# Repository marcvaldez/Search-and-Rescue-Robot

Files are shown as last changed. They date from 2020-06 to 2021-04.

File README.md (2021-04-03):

# Search-and-Rescue-Robot
A project created as a requirement for my mechatronics class in NBCC

Click on the image below to see the robot in action.

<a href="http://www.youtube.com/watch?feature=player_embedded&v=D-dJUbFVb4I
" target="_blank">Search and Rescue Robot</a>

Click on the image below for an overview
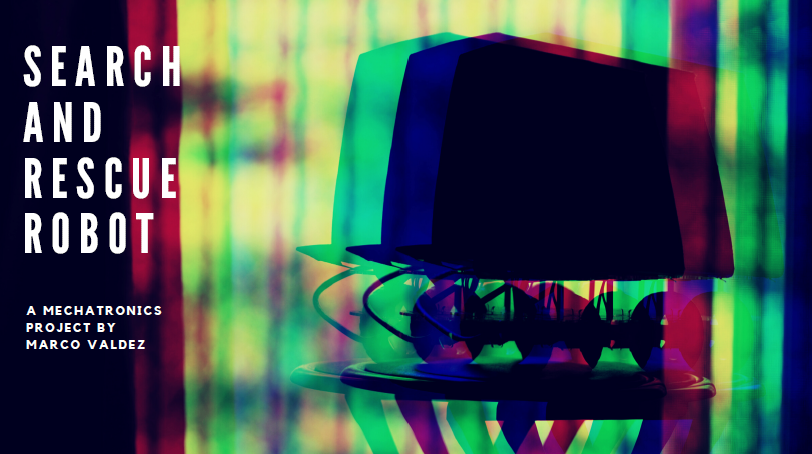
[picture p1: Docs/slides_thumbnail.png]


## Features

- Can be controlled via wi-fi using a laptop or phone or any device that has a browser
- Has a camera for first-person view
- Has collision detection through the ultrasonic sensor so that it would automatically stop when it's about to hit an obstacle
- Able to recognize specific objects to assist in searching (via an external object detection server)
- Armed with a foam dart pistol and laser module for dealing with threats

## Controls

- Forward
- Backward
- Turn Left
- Turn Right
- Nudge Left
- Nudge Right
- Stop
- Toggle Laser
- Fire Weapon

## Parts

- Arduino Uno
- ESP32-Cam microcontroller
- Robot Car Chassis with 4x DC motors and gearboxes (without motor driver circuitboard)
- 4-channel relay
- USB Power Bank
- Laser Module
- Ultrasonic Sensor
- Micro servo
- Ceramic capacitors
- Foam dart gun
- Breadboard

## Installation

### Step 1

Follow the steps in this YouTube tutorial by Edje Electronics

<a href="http://www.youtube.com/watch?feature=player_embedded&v=Rgpfk6eYxJA
" target="_blank">Object Detection Tutorial Video Thumbnail</a>

on how to create a Tensorflow v1 environment and train an object detection model to be able to recognize your "search targets".

Tip: I found that running `conda install tensorflow-gpu=1.15.0` is a quick shortcut to setting up your tensorflow environment. No need to install CUDA or cuDNN, etc.

### Step 2

Copy `object_detection_server.py` from this project into your `tensorflow/models/research/object_detection` folder and run it.

### Step 3

Modify `Arduino/RobotEye/index.html` and replace the values for cam_ws and ai_ws with the intended IP addresses of your robot server and object detection server.

This `index.html` will serve as the "remote control" or UI of the robot. You have two options on where to host this html file:

#### Option 1 - Hosting the UI on the image detection server

Just copy the modified file over to the same location where you copied `object_detection_server.py` which is your `tensorflow/models/research/object_detection` folder.

#### Option 2 - Hosting the UI on the robot itself

This step is a bit more involved. First, compress all the text content of the modified `index.html` using gzip and encode it in a comma-separated hex (0x00) format. You can do this easily using [CyberChef](https://gchq.github.io/CyberChef).

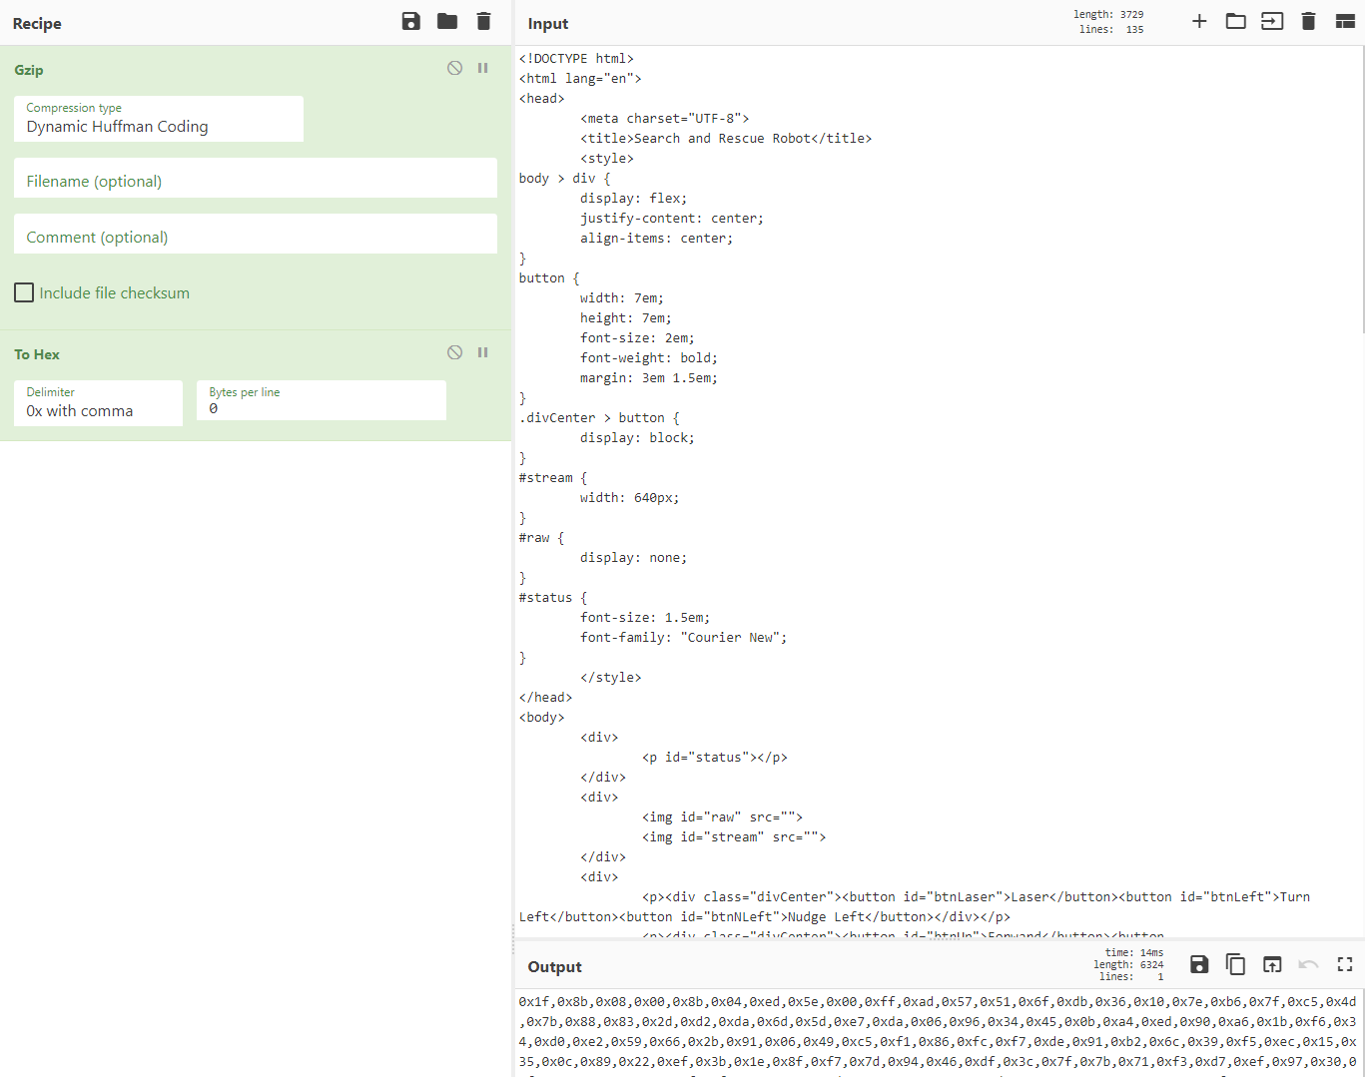
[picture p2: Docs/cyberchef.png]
CyberChef screenshot


Then, modify the `Arduino/RobotEye/camera_index.h` and replace all the hex code with the output from CyberChef. Don't forget to change the value of `index_ov2640_html_gz_len` to the number of hex codes you got. (I usually just paste all the hex code in Notepad++ and find the last column and divide by 5.)

#### Bonus Option - Do both options

### Step 4

Modify `Arduino/RobotEye/RobotEye.ino` by putting your wi-fi SSID and password into the code.

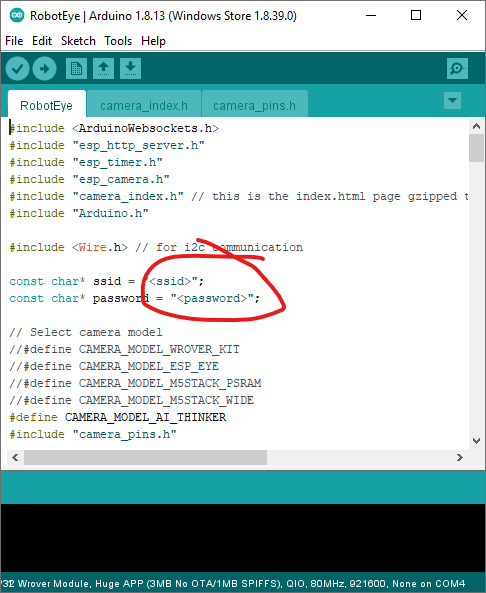
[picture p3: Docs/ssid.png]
Robot eye code screenshot


Make sure you have the ESP32 boards installed in the Arduino IDE. If not, go to `File-Preferences` and make sure `https://dl.espressif.com/dl/package_esp32_index.json` is included under `Additional Boards Manager URLs`.

Board manager

Upload `Arduino/RobotEye/RobotEye.ino` to the ESP32-Cam. Use ESP32 Wrover Module as the board when uploading. Try to use a partition with a high enough space for the app. "Huge App" works fine.

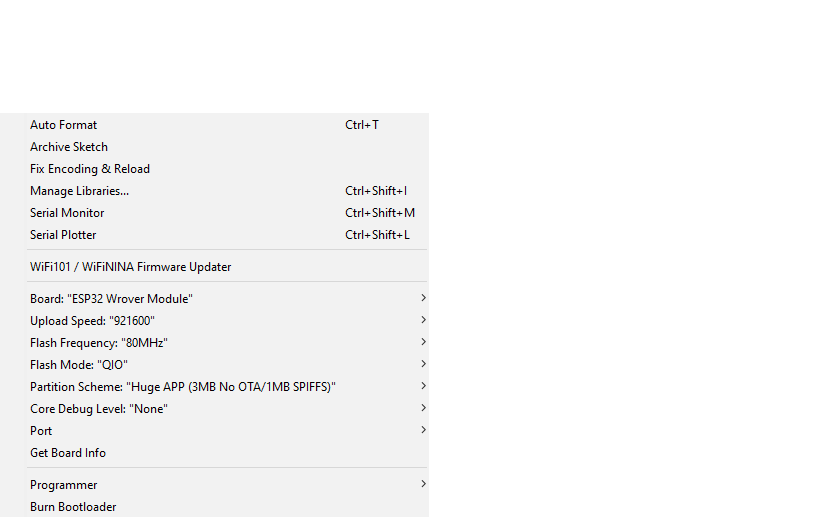
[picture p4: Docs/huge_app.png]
Upload screen


If you do not have an FTDI programmer or any other way to upload code to the ESP32-Cam. Refer to the tutorial below on how to program the ESP32-Cam using just the Arduino Uno.

https://create.arduino.cc/projecthub/PMGOHARIAN/setting-up-esp-cam-with-arduino-no-more-usb-ttl-35467a

### Step 5

Upload `Arduino/RobotEngine/RobotEngine.ino` to the Arduino Uno.

### Step 6

Wire everything up using the Fritzing diagram in `Docs\Search_and_Destroy_Robot.fzz`
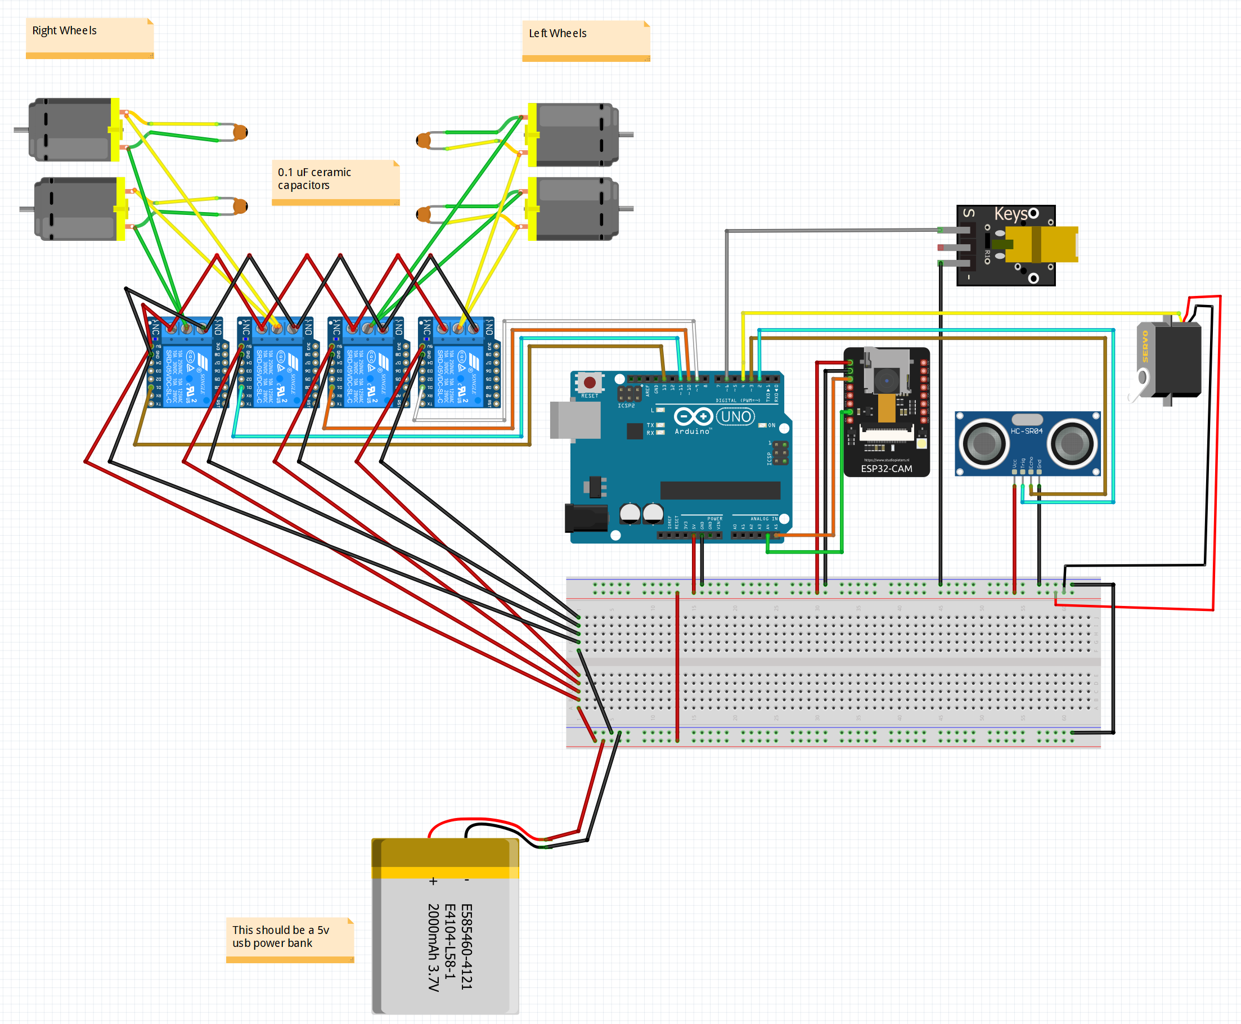
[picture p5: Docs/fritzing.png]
Fritzing Diagram


### Step 7

Navigate to wherever you hosted the "Remote Control" UI html page from step 3 using your browser and enjoy searching and rescuing.

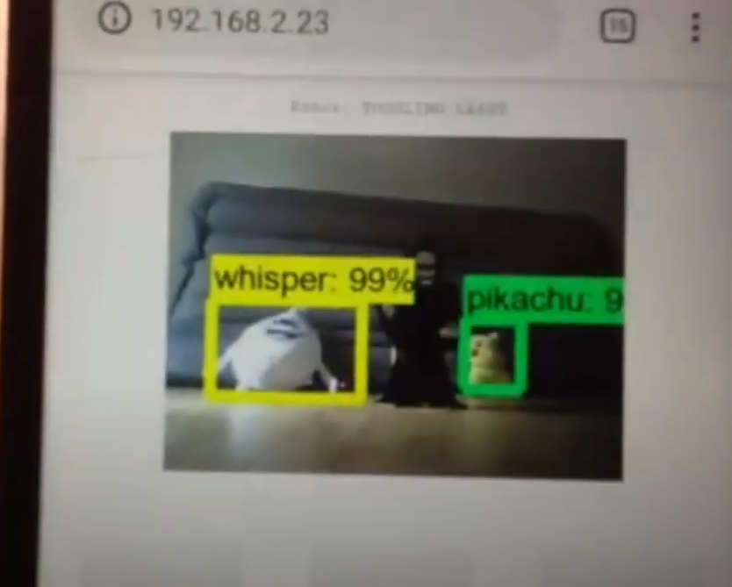
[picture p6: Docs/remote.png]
Remote UI image


## References

DC Motor Controller with Two Relays
https://www.instructables.com/id/DC-Motor-Controller-With-Two-Relay/

Programming ESP32-CAM with the Arduino Uno Without FTDI or USB-TTL
https://create.arduino.cc/projecthub/PMGOHARIAN/setting-up-esp-cam-with-arduino-no-more-usb-ttl-35467a

I2C Between Arduinos
https://www.instructables.com/id/I2C-between-Arduinos/

Editing the ESP32-CAM Camera Web Server HTML
https://robotzero.one/esp32-cam-custom-html/

Tensorflow Object Detection Tutorial
https://github.com/EdjeElectronics/TensorFlow-Object-Detection-API-Tutorial-Train-Multiple-Objects-Windows-10

How to Create a Simple Python WebSocket Server Using Tornado
https://www.toptal.com/tornado/simple-python-websocket-server

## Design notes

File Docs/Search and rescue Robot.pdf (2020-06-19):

# A M E C H A T R O N I C S P R O J E C T B Y M A R C O V A L D E Z

# SEARCH AND RESCUE ROBOT

# FEATURES

Can be controlled via wi-fi using a laptop or phone or any

device that has a browser

Has a camera for first-person view

Has collision detection through the ultrasonic sensor so that it

would automatically stop when it's about to hit an obstacle

Able to recognize specific objects to assist in searching (via an

object detection server)

Armed with a foam dart pistol and laser module for dealing with

threats

Forward

Backward

Turn Left

Turn Right

Nudge Left

Nudge Right

Stop
Toggle Laser

Fire Weapon

# CONTROLS

# HOW IT WORKS

### Device with Browser

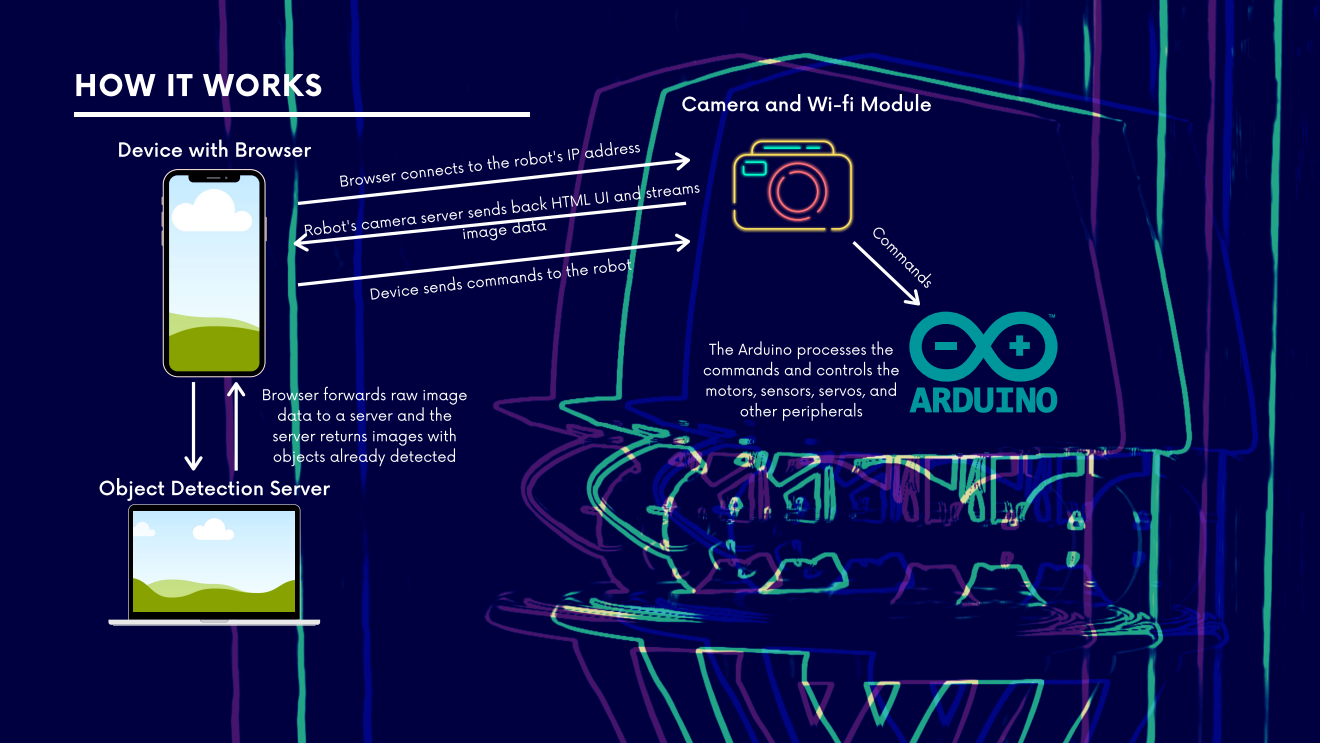
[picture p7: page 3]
image data; Commands; other peripherals

Camera and Wi-fi Module

Browser connects to the robot's IP address

Robot's camera server sends back HTML UI and streams

Device sends commands to the robot

The Arduino processes the
commands and controls the
motors, sensors, servos, and

Browser forwards raw image
data to a server and the
server returns images with
objects already detected

Object Detection Server

# PARTS

Arduino Uno

ESP32-Cam microcontroller - https://www.amazon.ca/gp/product/B07WTBTKDM

Robot Car Chassis with 4x DC motors and gearboxes - https://www.amazon.ca/gp/product/B075LD4FPN

4-channel relay - https://www.amazon.ca/gp/product/B072XGF4Z3

USB Power Bank

Laser Module

Ultrasonic Sensor

Micro servo

Ceramic capacitors

Foam dart gun

Breadboard

# REFERENCES

DC Motor Controller with Two Relays https://www.instructables.com/id/DC-Motor-Controller-With-Two-Relay/

Programming ESP32-CAM with the Arduino Uno Without FTDI or USB-TTL https://create.arduino.cc/projecthub/PMGOHARIAN/setting-up-esp-cam-with-arduino-no-more-usb-ttl-35467a

I2C Between Arduinos
https://www.instructables.com/id/I2C-between-Arduinos/

Editing the ESP32-CAM Camera Web Server HTML https://robotzero.one/esp32-cam-custom-html/

Tensorflow Object Detection Tutorial https://github.com/EdjeElectronics/TensorFlow-Object-Detection-API-Tutorial-Train-Multiple-Objects-Windows-10

How to Create a Simple Python WebSocket Server Using Tornado https://www.toptal.com/tornado/simple-python-websocket-server

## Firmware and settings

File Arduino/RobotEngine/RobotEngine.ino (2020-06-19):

#include <Servo.h>

#include <Wire.h> // for i2c communication

#define I2C_BUS 0x09 // arbitrary unused address in I2C

#define PIN_SERVO 4
#define PIN_LASER 6
#define PIN_TRIG 2
#define PIN_ECHO 3

// pins for controlling the relays
#define PIN_L1 9
#define PIN_L2 10
#define PIN_R1 11
#define PIN_R2 13

Servo myservo;

volatile bool laser_state = false;

int msg; // message from i2c bus

float cm;

void setup() {
  Serial.begin(9600);

  pinMode(PIN_L1, OUTPUT);
  pinMode(PIN_L2, OUTPUT);
  pinMode(PIN_R1, OUTPUT);
  pinMode(PIN_R2, OUTPUT);

  pinMode(PIN_LASER, OUTPUT);

  // set initial state
  robot_stop();

  myservo.attach(PIN_SERVO);
  myservo.write(90);

  // start the i2c bus as slave
  Wire.begin(I2C_BUS);
  // attach delegate for receiving messages
  Wire.onReceive(receiveEvent);
}

void loop() {
  if (msg == 1) {
    forward();
  }
  else if (msg == 2) {
    reverse();
  }
  else if (msg == 3) {
    turn_left();
  }
  else if (msg == 4) {
    turn_right();
  }
  else if (msg == 5) {
    robot_stop(); // stop first before firing
    fire_gun();
  }
  else if (msg == 6) {
    toggle_laser();
  }
  else if (msg == 7) {
    nudge_left();
  }
  else if (msg == 8) {
    nudge_right();
  }
  else {
    robot_stop();
  }
  sense_collission();
  delay(100);
}

void receiveEvent(int bytes) {
  msg = Wire.read();    // read one character from the I2C bus
}

void fire_gun() {
    Serial.println("fire!");

    myservo.write(0);
    delay(200);
    myservo.write(90);
    robot_stop();
}

void robot_stop() {
    digitalWrite(PIN_L1, LOW);
    digitalWrite(PIN_L2, LOW);
    digitalWrite(PIN_R1, LOW);
    digitalWrite(PIN_R2, LOW);
    //Serial.println("stop");
    msg = 0;
}

void forward() {
    digitalWrite(PIN_L1, LOW);
    digitalWrite(PIN_L2, HIGH);
    digitalWrite(PIN_R1, LOW);
    digitalWrite(PIN_R2, HIGH);
    //Serial.println("forward");
}

void reverse() {
    digitalWrite(PIN_L1, HIGH);
    digitalWrite(PIN_L2, LOW);
    digitalWrite(PIN_R1, HIGH);
    digitalWrite(PIN_R2, LOW);
    //Serial.println("backward");
}

void turn_left() {
    digitalWrite(PIN_L1, LOW);
    digitalWrite(PIN_L2, HIGH);
    digitalWrite(PIN_R1, HIGH);
    digitalWrite(PIN_R2, LOW);
    //Serial.println("left");
}

void turn_right() {
    digitalWrite(PIN_L1, HIGH);
    digitalWrite(PIN_L2, LOW);
    digitalWrite(PIN_R1, LOW);
    digitalWrite(PIN_R2, HIGH);
    //Serial.println("right");
}

void nudge_left() {
  turn_left();
  delay(100);
  robot_stop();
}

void nudge_right() {
  turn_right();
  delay(100);
  robot_stop();
}

void toggle_laser() {
  if (laser_state) {
    laser_state = false;
    digitalWrite(PIN_LASER, LOW);
  }
  else {
    laser_state = true;
    digitalWrite(PIN_LASER, HIGH);
  }
  robot_stop();
}

void sense_collission() {
  digitalWrite(PIN_TRIG, LOW);       
  delayMicroseconds(2);
  digitalWrite(PIN_TRIG, HIGH);
  delayMicroseconds(10);
  digitalWrite(PIN_TRIG, LOW);
  cm = pulseIn(PIN_ECHO, HIGH) / 58.0; //The echo time is converted into cm
  cm = (int(cm * 100.0)) / 100.0;     //Keep two decimal places
  Serial.print("Distance\t=\t");
  Serial.print(cm);
  Serial.print("cm");
  Serial.println();
  if (cm < 15 && cm > 2 && msg != 2) // stop when near obstacle (15 cm), filter outliers, reverse always allowed
    robot_stop();
}

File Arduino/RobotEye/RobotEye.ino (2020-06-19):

#include <ArduinoWebsockets.h>
#include "esp_http_server.h"
#include "esp_timer.h"
#include "esp_camera.h"
#include "camera_index.h" // this is the index.html page gzipped then converted to hex
#include "Arduino.h"

#include <Wire.h> // for i2c communication

const char* ssid = "<ssid>";
const char* password = "<password>";

// Select camera model
//#define CAMERA_MODEL_WROVER_KIT
//#define CAMERA_MODEL_ESP_EYE
//#define CAMERA_MODEL_M5STACK_PSRAM
//#define CAMERA_MODEL_M5STACK_WIDE
#define CAMERA_MODEL_AI_THINKER
#include "camera_pins.h"

using namespace websockets;
WebsocketsServer socket_server;

camera_fb_t * fb = NULL;

long current_millis;
long last_detected_millis = 0;

void app_httpserver_init();

httpd_handle_t camera_httpd = NULL;

// pins to communicate with arduino
#define PIN_SDA 2
#define PIN_SCL 12
#define I2C_BUS 0x09 // arbitrary unused address in I2C

//#define PIN_FORWARD 2
//#define PIN_REVERSE 12
//#define PIN_LEFT 13
//#define PIN_RIGHT 15

void setup() {
  Serial.begin(115200);
  Serial.setDebugOutput(true);
  Serial.println();

  // start the i2c bus as master
  Wire.begin(PIN_SDA, PIN_SCL); // use specified pins for i2c because sda and scl pins are not exposed in esp32-cam

// code below is from CameraServer example code
  camera_config_t config;
  config.ledc_channel = LEDC_CHANNEL_0;
  config.ledc_timer = LEDC_TIMER_0;
  config.pin_d0 = Y2_GPIO_NUM;
  config.pin_d1 = Y3_GPIO_NUM;
  config.pin_d2 = Y4_GPIO_NUM;
  config.pin_d3 = Y5_GPIO_NUM;
  config.pin_d4 = Y6_GPIO_NUM;
  config.pin_d5 = Y7_GPIO_NUM;
  config.pin_d6 = Y8_GPIO_NUM;
  config.pin_d7 = Y9_GPIO_NUM;
  config.pin_xclk = XCLK_GPIO_NUM;
  config.pin_pclk = PCLK_GPIO_NUM;
  config.pin_vsync = VSYNC_GPIO_NUM;
  config.pin_href = HREF_GPIO_NUM;
  config.pin_sscb_sda = SIOD_GPIO_NUM;
  config.pin_sscb_scl = SIOC_GPIO_NUM;
  config.pin_pwdn = PWDN_GPIO_NUM;
  config.pin_reset = RESET_GPIO_NUM;
  config.xclk_freq_hz = 20000000;
  config.pixel_format = PIXFORMAT_JPEG;
  //init with high specs to pre-allocate larger buffers
  if (psramFound()) {
    config.frame_size = FRAMESIZE_UXGA;
    config.jpeg_quality = 10;
    config.fb_count = 2;
  } else {
    config.frame_size = FRAMESIZE_SVGA;
    config.jpeg_quality = 12;
    config.fb_count = 1;
  }

#if defined(CAMERA_MODEL_ESP_EYE)
  pinMode(13, INPUT_PULLUP);
  pinMode(14, INPUT_PULLUP);
#endif

  // camera init
  esp_err_t err = esp_camera_init(&config);
  if (err != ESP_OK) {
    Serial.printf("Camera init failed with error 0x%x", err);
    return;
  }

  sensor_t * s = esp_camera_sensor_get();
  s->set_framesize(s, FRAMESIZE_QVGA);

#if defined(CAMERA_MODEL_M5STACK_WIDE)
  s->set_vflip(s, 1);
  s->set_hmirror(s, 1);
#endif

  WiFi.begin(ssid, password);
  while (WiFi.status() != WL_CONNECTED) {
    delay(500);
    Serial.print(".");
  }
  Serial.println("");
  Serial.println("WiFi connected");

  app_httpserver_init();
  socket_server.listen(82);

  Serial.print("Camera Ready! Use 'http://");
  Serial.print(WiFi.localIP());
  Serial.println("' to connect");
}

static esp_err_t index_handler(httpd_req_t *req) {
  httpd_resp_set_type(req, "text/html");
  httpd_resp_set_hdr(req, "Content-Encoding", "gzip");
  return httpd_resp_send(req, (const char *)index_ov2640_html_gz, index_ov2640_html_gz_len);
}

httpd_uri_t index_uri = {
  .uri       = "/",
  .method    = HTTP_GET,
  .handler   = index_handler,
  .user_ctx  = NULL
};

void app_httpserver_init ()
{
  httpd_config_t config = HTTPD_DEFAULT_CONFIG();
  if (httpd_start(&camera_httpd, &config) == ESP_OK)
    Serial.println("httpd_start");
  {
    httpd_register_uri_handler(camera_httpd, &index_uri);
  }
}

// sending commands to the arduino using I2C wires
void handle_message(WebsocketsClient &client, WebsocketsMessage msg)
{
  Wire.beginTransmission(I2C_BUS);
  if (msg.data() == "stop") {
    Wire.write(0);
    client.send("STOPPING");
  }
  if (msg.data() == "forward") {
    Wire.write(1);
    client.send("MOVING");
  }
  if (msg.data() == "reverse") {
    Wire.write(2);
    client.send("REVERSING");
  }
  if (msg.data() == "left") {
    Wire.write(3);
    client.send("TURNING LEFT");
  }
  if (msg.data() == "right") {
    Wire.write(4);
    client.send("TURNING RIGHT");
  }
  if (msg.data() == "fire") {
    Wire.write(5);
    client.send("FIRING");
  }
  if (msg.data() == "laser") {
    Wire.write(6);
    client.send("TOGGLING LASER");
  }
  if (msg.data() == "nleft") {
    Wire.write(7);
    client.send("NUDGING LEFT");
  }
  if (msg.data() == "nright") {
    Wire.write(8);
    client.send("NUDGING RIGHT");
  }
  Wire.endTransmission();
}

void loop() {
  auto client = socket_server.accept();
  client.onMessage(handle_message);

  client.send("STREAMING");

  while (client.available()) {
    client.poll();

    fb = esp_camera_fb_get();

    client.sendBinary((const char *)fb->buf, fb->len);

    esp_camera_fb_return(fb);
    fb = NULL;
  }
}
